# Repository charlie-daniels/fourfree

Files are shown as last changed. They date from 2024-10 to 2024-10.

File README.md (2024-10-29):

# fourfree - 43 key keeb

Designed because nobody sells 40-ish percent keyboards anymore.

## PCB

Created using KiCad with [marbastlib](https://github.com/ebastler/marbastlib) and a few handmade footprints.

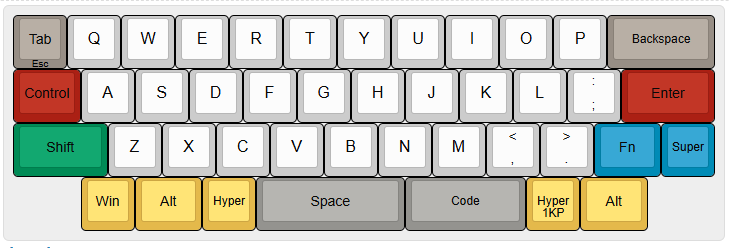
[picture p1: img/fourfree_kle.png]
kle layout


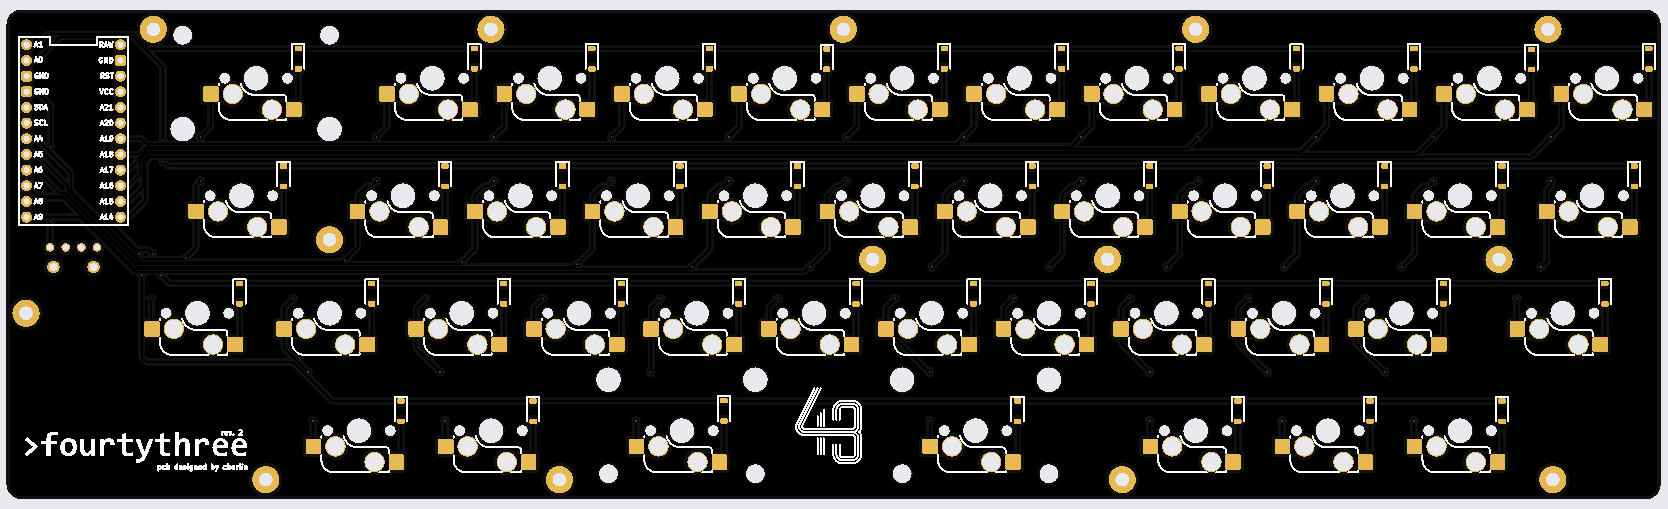
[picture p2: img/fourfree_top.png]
pcb top side


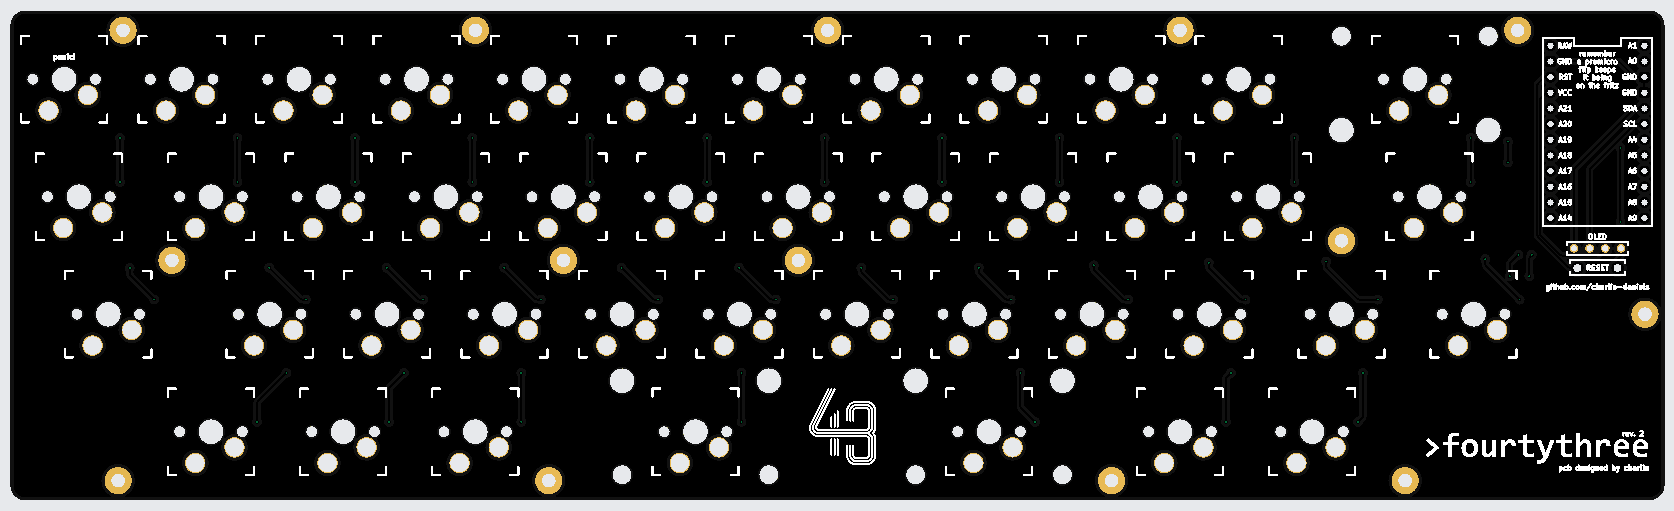
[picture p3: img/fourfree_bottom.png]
pcb bottom side


Created Oct 2024.

## Assembly

**ProMicro goes in upsidedown on the topside!!!**
This is why the pads are on the bottom and the pin labels seem flipped from the top.

### Components 

**PCB** 

- 43x 1N4148W Diodes
- 43x Kailh Hotswap MX
- 1x Sparkfun Promicro
- 1x 2-pin Reset switch
- 1x 128x32 OLED (optional)
- 1x 2.75u PCB mount stabiliser
- 1x 2.25u PCB mount stabiliser
- 1x 2u PCB mount stabiliser

**Case**

- 14x M2 screws...?
Case still being designed but should be screw in to the pcb mounting brackets, maybe 14 was overkill...

## Firmware

This is just initial firmware made with [Keyboard Firmware Builder](https://kbfirmware.com/) by [Ruiqi Mao](https://ruiqimao.com/). The keymaps should work as expected as they are configured properly with the pinouts and key matrix.

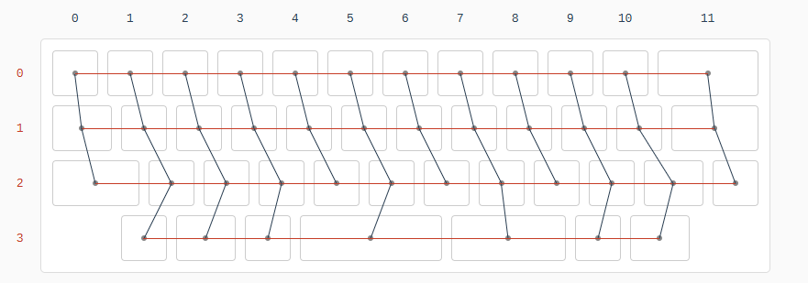
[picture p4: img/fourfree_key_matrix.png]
firmware key matrix


## In Progress...

- Plate
- Case
- To see if the pcb actually works...

## Thanks

[Ben Vallack](https://www.youtube.com/channel/UC4NNPgQ9sOkBjw6GlkgCylg)'s YouTube tutorials are great.

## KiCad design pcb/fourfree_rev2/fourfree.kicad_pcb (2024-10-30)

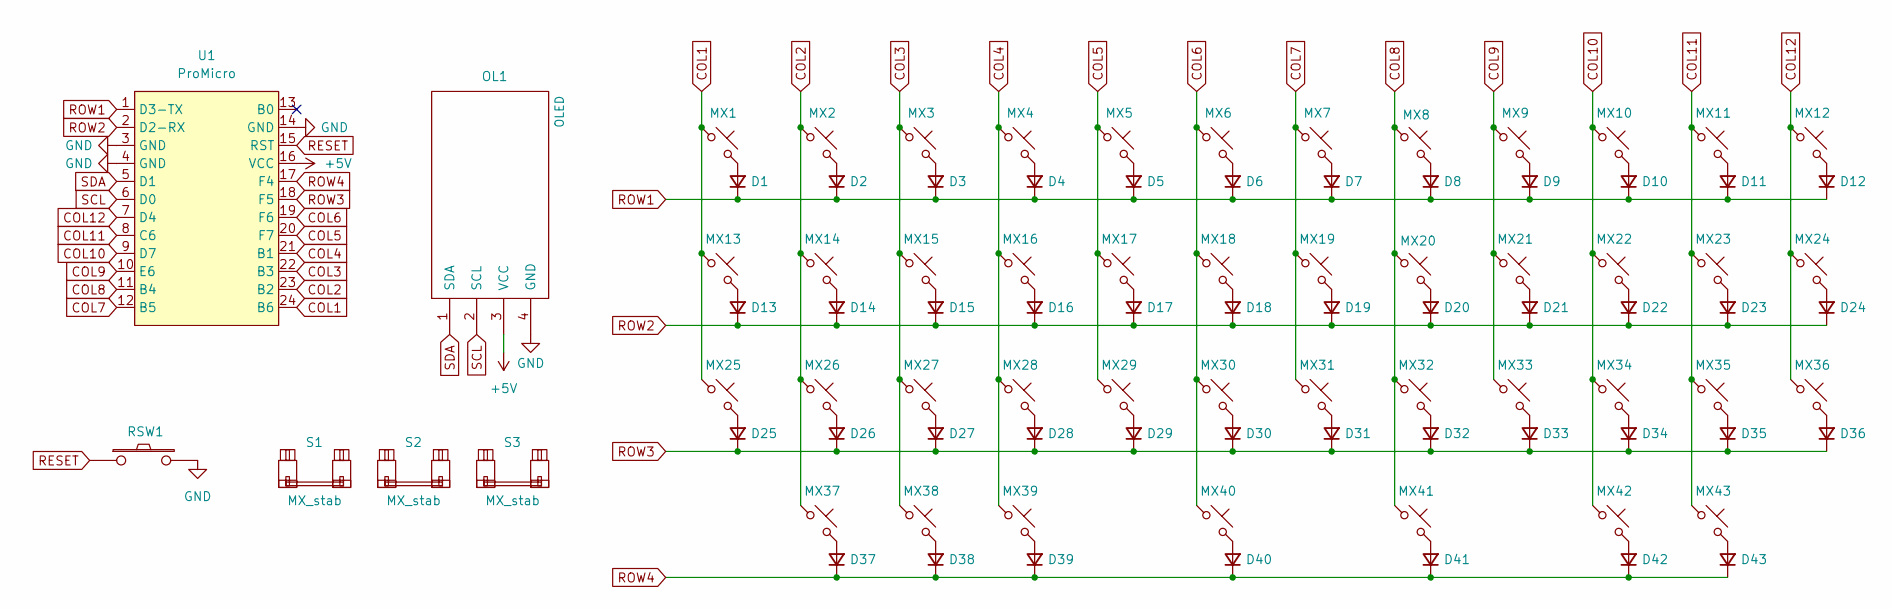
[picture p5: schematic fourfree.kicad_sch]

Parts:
D1, D2, D3, D4, D5, D6, D7, D8, D9, D10, D11, D12, D13, D14, D15, D16, D17, D18, D19, D20, D21, D22, D23, D24, D25, D26, D27, D28, D29, D30, D31, D32, D33, D34, D35, D36, D37, D38, D39, D40, D41, D42, D43: D_Small; D_SOD-123
MX1, MX2, MX3, MX4, MX5, MX6, MX7, MX8, MX9, MX10, MX11, MX12, MX14, MX15, MX16, MX17, MX18, MX19, MX20, MX21, MX22, MX23, MX26, MX27, MX28, MX29, MX30, MX31, MX32, MX33, MX34, MX36, MX37, MX39, MX40, MX41, MX42: MX_SW_solder; SW_MX_HS_CPG151101S11_1u
MX13, MX35, MX38, MX43: MX_SW_solder; SW_MX_HS_CPG151101S11_1.25u
MX24, MX25: MX_SW_solder; SW_MX_HS_CPG151101S11_1.75u
OL1: OLED
RSW1: SW_PUSH; ResetSW
S1: MX_stab; STAB_MX_2.75u
S2: MX_stab; STAB_MX_2u
S3: MX_stab; STAB_MX_2.25u
U1: ProMicro; ProMicro_USBup

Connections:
+5V: OL1.3 (VCC), U1.16 (VCC)
COL1: MX1.1, MX13.1, MX25.1, U1.24 (B6)
COL2: MX2.1, MX14.1, MX26.1, MX37.1, U1.23 (B2)
COL3: MX3.1, MX15.1, MX27.1, MX38.1, U1.22 (B3)
COL4: MX4.1, MX16.1, MX28.1, MX39.1, U1.21 (B1)
COL5: MX5.1, MX17.1, MX29.1, U1.20 (F7)
COL6: MX6.1, MX18.1, MX30.1, MX40.1, U1.19 (F6)
COL7: MX7.1, MX19.1, MX31.1, U1.12 (B5)
COL8: MX8.1, MX20.1, MX32.1, MX41.1, U1.11 (B4)
COL9: MX9.1, MX21.1, MX33.1, U1.10 (E6)
COL10: MX10.1, MX22.1, MX34.1, MX42.1, U1.9 (D7)
COL11: MX11.1, MX23.1, MX35.1, MX43.1, U1.8 (C6)
COL12: MX12.1, MX24.1, MX36.1, U1.7 (D4)
GND: OL1.4 (GND), RSW1.2, U1.3 (GND), U1.4 (GND), U1.14 (GND)
unnamed: D1.2 (A), MX1.2
unnamed: D2.2 (A), MX2.2
unnamed: D3.2 (A), MX3.2
unnamed: D4.2 (A), MX4.2
unnamed: D5.2 (A), MX5.2
unnamed: D6.2 (A), MX6.2
unnamed: D7.2 (A), MX7.2
unnamed: D8.2 (A), MX8.2
unnamed: D9.2 (A), MX9.2
unnamed: D10.2 (A), MX10.2
unnamed: D11.2 (A), MX11.2
unnamed: D12.2 (A), MX12.2
unnamed: D13.2 (A), MX13.2
unnamed: D14.2 (A), MX14.2
unnamed: D15.2 (A), MX15.2
unnamed: D16.2 (A), MX16.2
unnamed: D17.2 (A), MX17.2
unnamed: D18.2 (A), MX18.2
unnamed: D19.2 (A), MX19.2
unnamed: D20.2 (A), MX20.2
unnamed: D21.2 (A), MX21.2
unnamed: D22.2 (A), MX22.2
unnamed: D23.2 (A), MX23.2
unnamed: D24.2 (A), MX24.2
unnamed: D25.2 (A), MX25.2
unnamed: D26.2 (A), MX26.2
unnamed: D27.2 (A), MX27.2
unnamed: D28.2 (A), MX28.2
unnamed: D29.2 (A), MX29.2
unnamed: D30.2 (A), MX30.2
unnamed: D31.2 (A), MX31.2
unnamed: D32.2 (A), MX32.2
unnamed: D33.2 (A), MX33.2
unnamed: D34.2 (A), MX34.2
unnamed: D35.2 (A), MX35.2
unnamed: D36.2 (A), MX36.2
unnamed: D37.2 (A), MX37.2
unnamed: D38.2 (A), MX38.2
unnamed: D39.2 (A), MX39.2
unnamed: D40.2 (A), MX40.2
unnamed: D41.2 (A), MX41.2
unnamed: D42.2 (A), MX42.2
unnamed: D43.2 (A), MX43.2
RESET: RSW1.1, U1.15 (RST)
ROW1: D1.1 (K), D2.1 (K), D3.1 (K), D4.1 (K), D5.1 (K), D6.1 (K), D7.1 (K), D8.1 (K), D9.1 (K), D10.1 (K), D11.1 (K), D12.1 (K), U1.1 (D3-TX)
ROW2: D13.1 (K), D14.1 (K), D15.1 (K), D16.1 (K), D17.1 (K), D18.1 (K), D19.1 (K), D20.1 (K), D21.1 (K), D22.1 (K), D23.1 (K), D24.1 (K), U1.2 (D2-RX)
ROW3: D25.1 (K), D26.1 (K), D27.1 (K), D28.1 (K), D29.1 (K), D30.1 (K), D31.1 (K), D32.1 (K), D33.1 (K), D34.1 (K), D35.1 (K), D36.1 (K), U1.18 (F5)
ROW4: D37.1 (K), D38.1 (K), D39.1 (K), D40.1 (K), D41.1 (K), D42.1 (K), D43.1 (K), U1.17 (F4)
SCL: OL1.2 (SCL), U1.6 (D0)
SDA: OL1.1 (SDA), U1.5 (D1)

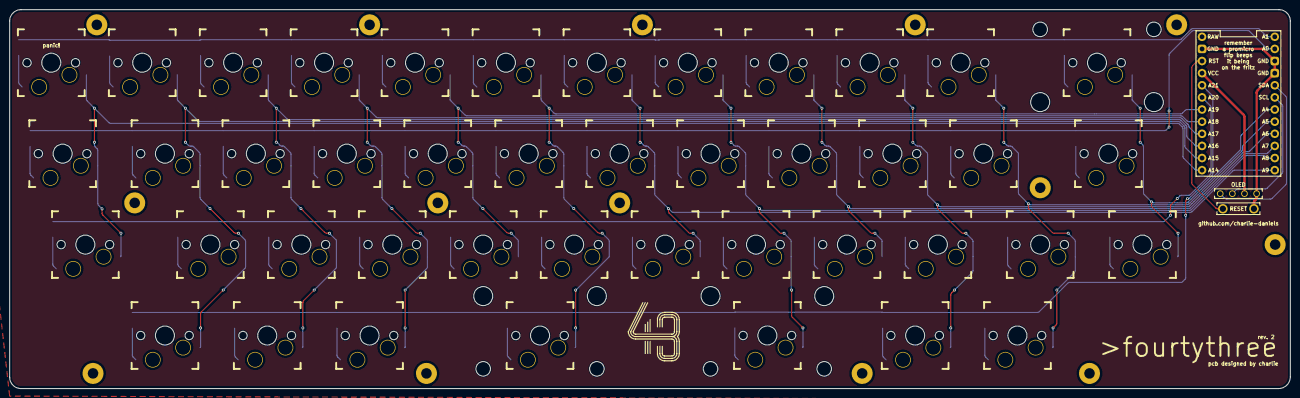
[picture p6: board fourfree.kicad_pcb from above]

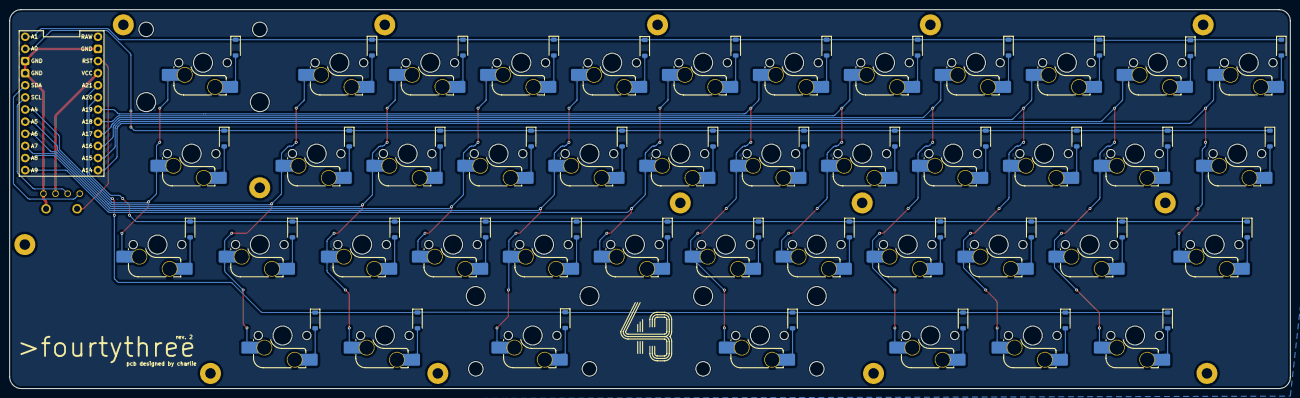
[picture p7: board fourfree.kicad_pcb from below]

Board: 2 copper layers, 268.3 x 79.4 mm, 92 parts (87 on the bottom side), 64 nets.

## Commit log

2024-10-28 Add pcb
    [fourfree.kicad_pcb, fourfree.kicad_sch]
2024-10-28 add pcb images
2024-10-30 thicken power netclass tracks
    [fourfree.kicad_pcb]
2024-10-30 add missing kicad files
2024-10-30 update gerber
